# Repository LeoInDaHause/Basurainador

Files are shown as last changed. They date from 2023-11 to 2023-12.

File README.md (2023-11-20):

# Integrantes
Cesar Leonardo Rodriguez León

Diego Fernando Carvajal Lagos

Jhohan Stiven Rodriguez Rodriguez

# BASURA-INADOR

Este proyecto que tiene como objetivo central crear una cultura positiva alrededor de las basuras, en esto se trata sobre el reciclaje y el manejo de las basuras. con el objetivo de lograr esto se crea un "artefacto" que sea didactico y que llame la atención de niños entre los 5 a 7 años.

Para lograr construir este proyecto "artefacto", se a realizado una investigación previa, alrededor de la cultura y de como contruir esta cultura en los niños. y tambien se realizo una investigación sobre los materiales para usar, y de la manera mas eficiente de conseguir este artefacto.

las concluciones obtenidas de estas investigaciones son:

1. Por parte de lo cultural, se identificó que la mejor manera de crear una cultura en los niños eran son estímulos que a estos les llamara la atención, por ejemplo luces y sonidos.

2. A partir de la investigación realizada para temas de material y eficiencia del proyecto, de decide el uso de un microcontrolador, junto a un sensor de color, luces led, y sonidos.

En un principio se tenia la idea de realizar 3 canecas de basura que tubieran el objetivo de separar las basuras, en organicos, papel y carton, y metales y vidrios. A medida que fue avanzando el tiempo el proyecto cada vez era mas pulido. hasta el punto en el que unicamente se utilizaria una caneca, y a partir de esto, mediante una pantalla(lcd o oled), se le pidiera al usuario ingresear un tipo de basura, mediante un sensor (TCS3200) detectaria el color de la basura y determinaria, mediante un programa desde el microcontrolador (ESP32), si este elemento es el solicitado o no. en caso de que el elemento fuera correcto, este arrojaria la LUZ del elemento y produciria un sonido "positivo", y habriria la tapa de la caneca, en caso contrario este arrojaria una LUZ diferente al elemento y produciria un sonido "malo", y la tapa no habriría.

De esta manera se espera que el niño de 5 a 7 años interactue con el "artefacto" sin aburrirse, y genernado en este la cultura deseada, para solucionar una problematica que se vive en la actualidad y que tiene graves consecuencias, como lo es el impacto a la salud, clima, biodiversidad, suciedad, entre otras cosas.

Las teorias que sustentan este proyecto son fisicas orientadas a la elecctronica, y sociales orientadas a la cultura.

## Teorias orientadas a la electrónica:
1. Leyes de Ohm
2. Leyes de Kirchhoff
3. Leyes de Maxwell
4. Teoria de telecomunicaciones
5. Teoria del control

## Teoria orientadas a la cultura:
1. Teoria del juego
2. Condicionamiento Clasico
3. Condicionamiento Operante
4. Teoría de la actividad de Elkonin

# Diagrama de Flujo:

Diagrama en blanco

# Diagrama de Caja negra:


# Diagrama de Tecnológico:

Basurainado diagrama refinado_page-0001

# Póster:

Plantilla_TPI pptx

# Proyecto Finalizado:

(video)

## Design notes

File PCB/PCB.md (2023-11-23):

# Creación de la PCB

Para la creación de la PCB, se empezo a realizar en las 3 ultimas semanas, esta cuando ya teniamos planteado de manera definitiva el proyecto, para el comienzo de la PCB se aprendio sobre las etiquetas utilizadas en kicat, para que se viera mas organizado la PCB:



Después, se empezaron a crear los caminos(tracks) para comunicar los componentes, en la imagen se puede ver como:









La siguiente imagen, se trata sobre el diametro de cada camino para el voltaje y los normales:



PCB ya en fisico




PCB con sus componenetes ya soldados




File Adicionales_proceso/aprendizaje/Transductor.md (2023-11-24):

Al comienzo del proceso teniamos pensado poner un parlante pequeño que trasmitiera sonidos a partir de si el elemento era correcto o no, a lo largo del proceso este objetivo quedo
al final, por lo cual la ultima semana, empezamos a cacharrear con el parlante. pero hubo un problema.

resulta que cuando poniamos el parlante en el proyecto, junto a los otros componentes, pensabamos que este como que consumia mayor voltaje haciendo que el servomotor se volviera loco y perdieramos
el control de este. por lo cual habiamos desistido debido a que ya teniamos el tiempo sobre el cuello, pero un dia antes de la presentacion, se detecto de que trataba el error.

este error se producia por un PIN

este fue por que usamos un PIN que ya estaba definido en el codigo, produciendo una mala señal y comprometiendo el servomotor
ya despues, detectado este error, se corrigio, por lo que al final nos quedamos con el PIN PWM (señal que genera al parlante para que reproduzca el sonido)

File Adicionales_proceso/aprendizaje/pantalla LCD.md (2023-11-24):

configuracion de la Pantalla LCD

con la pantalla LCD se tubo un problema con respecto a su conexion en un principio debido a que se necesitaba un cable 
especial que no se pudo conseguir, por lo que se tubo que soldar.



ya soldada los cables a la pantalla lcd se empiza a relaizar la programacion para que esta proyectara lo que queriamos,
en este caso producir un mensaje aleatorio solicitandole al usuario un elemento(basura) entre ("Organico", "Papel y Metal",
"Plastico y Vidrio"), y dependiendo de si es correcto esta daria un mensaje "Correcto" y en otro caso "Incorrecto"

https://github.com/LeoInDaHause/Basurainador/assets/145580263/93dd53f0-decb-44f5-940f-e1c6dde341c4

despues cuando se intento ya el proyecto completo hubo un fallo en la pantalla LCD, este se produjo debido a que un cable (jumper)
se habia dañado, haciendo que el computador no reconozca o no detecte la pantalla.

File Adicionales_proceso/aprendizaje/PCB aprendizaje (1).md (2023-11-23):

el proceso de la PCB, se realizo por medio de la aplicación kicad, esto debido a que nos permite hacer modelos esquematicos y de diseño, primero de hizo la programacion y conexion del circuito,todo conectado con la ESP32, despues toco escoger en cada uno de los componentes el modelo de (bluprint). despues en kicad no existia el diseño del sensor que usamos (TCS3200), por lo que toco diseñarlo, y por parte de la ESP32, se encontro el modelo por internet.

Despues se convierte el esquematico a brupint el cual hay que unir los camino de los cuales se escogieron, de igual que establecer su diametro. en este punto es muy importante por que hay que tener mucho cuidado de no cruzar los caminos, que estubieran diferentes para saber lo que iba conectado a que.

ya Finalizo el proceso de las capas de la PCB, esta se envio a una empresa en Bogotá que hace la PCB que fue diseñada, esta nos la entregan el lunes (20-11-2023) a las 5pm

ya con la PCB en nuestras manos de procedio a la soldar los componentes que le pusimos



despues de soldar, se limpio con alchol isopropilico para eliminar residuos de soldadura de nuestra PCB

https://github.com/LeoInDaHause/Basurainador/assets/145580263/677bf93b-1ecc-4082-81b1-64d2f14283ff

cuando probamos el proyecto en la PCB, no funcionaba, por lo que dudamos de si la PCB, quedo bien hecho, por lo que empezamos a mirar su continuidad

https://github.com/LeoInDaHause/Basurainador/assets/145580263/6830ea95-e548-415c-8a15-80466148f962

## Errores que tubimos en este proceso

1. en la creacion de la PCB, por medio de kicad, hubo mala conexion de los pines por lo cual arrojaba errores
2. otro problema fue el desconocimiento con la aplicacion que complico las cosas, pero con la ayuda del profesor este camino se
   fue despejando y haciendose mas facil

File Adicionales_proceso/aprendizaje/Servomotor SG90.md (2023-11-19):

mpiza la configuracion del servomotor

https://github.com/LeoInDaHause/Basurainador/assets/145580263/3488bf7d-7020-4524-8e29-eb3a34d98795

ya configurado correctamente el servomotor se prosigue con la configuacion de la pantalla LCD

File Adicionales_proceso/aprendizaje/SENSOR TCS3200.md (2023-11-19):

uando se configuro la ESP32 con el Sensor TCS3200, se empezo a detectar un problema que en un principo no sabiamos su causa, 
este problema se trataba sobre los valores que arrojaba la TCS3200 cuando se intentaba determinar un color, debido a que 
eran valores que variaban a cada segundo y de una manera aleatoria, (paralelo a esto tambien exisatian errores de programación)
esto de detecto cuando se reviso lo que sucedia en el osciloscopio.
La razón de este problema era debido al ruido que habia habia en el ambiente (luz natural o luz de los bombillos)
por lo cual nos dimos de cuenta de que para que el sensor funcione correctamente este debia de estar en cierta oscuridad, 
por lo que nuestro proyecto debe de estar en lugares cerrados.



Cuando se consiguio solucionar los problemas tanto de programacion como de iluminación, se prosiguio a hacer el servomotor

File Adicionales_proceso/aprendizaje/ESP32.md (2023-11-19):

comienza el proceso de (configurar) la ESP32 con el computador y con micropython,

ESP32 configuración

3. ya configurado la ESP32, se empieza a revisar los pines para realizar las conexiones, para esto se utilizo una Guia



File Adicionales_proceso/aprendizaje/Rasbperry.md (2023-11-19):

en un principio al empezar con el microcontrolador se empezo por una raspberry pi pico, en este proceso mediante un 
computador se utilizaron librerias que funcionaran para el Programa de programacion en este caso el usado fue Thonny.

se empieza la configuración de la raspberry

los problemas que se tubieron con la raspberry pi pico:

en este desarrollo se experimentaron diferentes problemas, debido a que se tubo que instalar diferentes archivos, 
y pedir permisos al computador para poderlos ejecutar, ya teniendo la rasbperry pi pico conectada al computador y 
a Thonny se empezo a cacharrear el funcionamiento con los pines mediante actividades durante el taller. nos guiamos
mediante el datacheet y de diferentes paginas encontradas en internet, la inmensa mayoria en ingles.

se enciende el sensor con la raspberry
se empieza a cacharrearle al sensor TCS3200, con la raspberry

Otro problema presentado fue a partir de intentar conectar los pines con los diferentes componentes en la protoboard, 
este problema se presentaba a razon de que no habia una buena conexion en la protoboard, lo que conllevaba a que 
aveces funcionaba y aveces no. En consecuencia de esto se decide soldar a los pines de la raspberry pi pico unas regletas, 
para poner conectar estas con jumpers hembra, debido a la inexperiencia la soldadura quedo mal, y la 
raspberry pi pico presento otros problemas 

pines soldados pico

despues de presentar los problemas anteriormente mencionado, se decidio en conjunto utilizar el microcontrolador ESP32, 
esto debido a que por una parte ya tiene las regletas soldadas, tambien porque esta mejor documentado por internet que 
la rasbperry pi pico, y ademas ya tiene mas bibliotecas

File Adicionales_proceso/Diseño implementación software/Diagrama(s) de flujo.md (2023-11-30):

El primer diagrama que se hizo, fue el diagrama de caja negra, este se define como un diagrma que muestra al usuario los diferentes mecanismos que hace un objeto, si recibe señales, y de esas señales también activa otras, estas señales puedes ser físicas, digitales, y lo mismo con los actuadores, y también define como este recibe energía, como transforma esa energía en señales y mensajes que recibe y manda, entre otras cosas.

Estos diagramas fueron evolucionando, a tal punto de crear un mejor diagrama de caja negra, de flujo:
Diagrama de caja negra #2:

Diagrama tecmológico:


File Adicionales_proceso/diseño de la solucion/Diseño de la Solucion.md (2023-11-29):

## Diagrama de Caja negra:


## Diagramas de Tecnológico:
# primer diagrama realizado

Basurainado diagrama refinado_page-0001

# segundo diagrama realizado

Basurainado diagrama refinado (1)

## Diagrama de Flujo:

Diagrama en blanco

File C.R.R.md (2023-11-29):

# Conclusiones
1. Para realizar un Proyecto como el que nos planteamos es necesario una Investigacion y Preparacion Posterior, de igual manera que debatir y tener una participacion activa en el proyecto.
   
2. Siempre debemos de mantener una Visión critica sobre lo que hacemos, es por esta razón que nuestra proyecto al pasar de tiempo fue variando poco a poco, mejorandolo cada vez mas. 
   
3. La prueba y error es fundamental para nuestro aprendizaje, la desesperacion y aveces un poco de estres nos permite ir mas halla de lo que creemos posible ir. a dia de hoy contamos con diferentes herramientas que nos permiten documentarnos, investigar y mejorarnos a si mismos, una de estas herramientas es la Internet, ya que es una gran fuente de conocimiento, que nos permite apoyarnos en ellas para salir de problemas en los que nos encontremos.

4. La tecnologia y en especial la Ingenieria Electronica, nos permite dar soluciones a diferentes problematicas alrededor del mundo, yendo desde lo mas tecnologico, hasta lo mas social.

5. La organizacion y un cronograma es fundamental para sacar adelante un proyecto

6. el profesor nos recomendo que cuando tubieramos problemas, miramos el problema de manera aislada, y no de manera conjunta, para esto debemos de mirar componente por componente, para identificar y aislar el problema que se nos presente

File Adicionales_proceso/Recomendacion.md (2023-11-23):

1. establecer un cronograma mas concreto
2. establecer mejor todo, y una mayor planificacion, para no gastar dinero de manera irracional
3. empezar desde el principio y no dejar gran parte a ultima hora
4. hacer pruebas en cada momento, para garantizar que el proyecto esta llendo por buen camino, y para identificar los errores a tiempo.

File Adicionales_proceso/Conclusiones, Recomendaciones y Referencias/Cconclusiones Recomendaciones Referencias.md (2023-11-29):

## Conclusiones
1. Para realizar un Proyecto como el que nos planteamos es necesario una Investigacion y Preparacion Posterior, de igual manera que debatir y tener una participacion activa en el proyecto.
   
2. Siempre debemos de mantener una Visión critica sobre lo que hacemos, es por esta razón que nuestra proyecto al pasar de tiempo fue variando poco a poco, mejorandolo cada vez mas. 
   
3. La prueba y error es fundamental para nuestro aprendizaje, la desesperacion y aveces un poco de estres nos permite ir mas halla de lo que creemos posible ir. a dia de hoy contamos con diferentes herramientas que nos permiten documentarnos, investigar y mejorarnos a si mismos, una de estas herramientas es la Internet, ya que es una gran fuente de conocimiento, que nos permite apoyarnos en ellas para salir de problemas en los que nos encontremos.

4. La tecnologia y en especial la Ingenieria Electronica, nos permite dar soluciones a diferentes problematicas alrededor del mundo, yendo desde lo mas tecnologico, hasta lo mas social.

5. La organizacion y un cronograma es fundamental para sacar adelante un proyecto

6. el profesor nos recomendo que cuando tubieramos problemas, miramos el problema de manera aislada, y no de manera conjunta, para esto debemos de mirar componente por componente, para identificar y aislar el problema que se nos presente

## Recomendaciones para proyectos futuros

1. establecer un cronograma mas concreto
   
2. establecer mejor todo, y una mayor planificacion, para no gastar dinero de manera irracional
   
3. empezar desde el principio y no dejar gran parte a ultima hora
   
4. hacer pruebas en cada momento, para garantizar que el proyecto esta llendo por buen camino, y para identificar los errores a tiempo.

## Referencias utlizadas para nuestro proyecto de investigacion

”Teor ́ıa del juego - Piaget, Vigotsky, Freud”, Web de
Psicolog ́ıa, 2019. [En l ́ınea]. Disponible: https://www.psicologia-
online.com/teoria-del-juego-piaget-vigotsky-freud-1427.html.
[  ́Ultimo acceso: 18-nov-2023]

M. Guerri, ”Skinner y en Condicionamiento Operante”,
PsicoActiva, 18-may-2023. [En l ́ınea]. Disponible:
https://www.psicoactiva.com/blog/skinner-condicionamiento-
operante/. [  ́Ultimo acceso: 18-nov-2023]

GestioPolis. “Teor ́ıa general de los sistemas”. [En l ́ınea].
Disponible en: https://www.gestiopolis.com/teoria-general-de-los-
sistemas/. [Accedido: 20-nov-2023]

Seg ́un un informe del Ministerio del Medio Ambiente de Chile,
los Objetivos de Desarrollo Sostenible (ODS) son de gran
importancia. [Enlace a la fuente: https://ods.mma.gob.cl/wp-
content/uploads/2017/06/12S panishW hyitM atters.pdf ]

Psicoactiva. (2023). Condicionamiento Cl ́asico. [Online]. Avail-
able: https://www.psicoactiva.com/blog/condicionamiento-clasico/

N ́ucleo do Conhecimento. (2023). Ense ̃nanza
del Desarrollo. [Online]. Available:
https://www.nucleodoconhecimento.com.br/educacion-
es/ensenanza-del-desarrollo/

J. Castells, "Teoría de las telecomunicaciones," Academia.edu, 2016. [En línea]. Disponible: https://www.academia.edu/29220037/Teor%C3%ADa_de_las_telecomunicaciones. [Accedido: 29-nov-2023]

"Introducción - Modelado," MdP, 2016. [En línea]. Disponible: http://www3.fi.mdp.edu.ar/control4c7/APUNTES/Clase%201%20-%20Introduccion%20-%20Modelado.pdf. [Accedido: 29-nov-2023]

"ESP32 Series Datasheet," Espressif Systems, 2023. [Online]. Available: https://www.espressif.com/sites/default/files/documentation/esp32_datasheet_en.pdf. [Accessed: 29-Nov-2023].

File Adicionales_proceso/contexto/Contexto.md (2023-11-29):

   ## Problematica

   La problematica que queremos atacar es la problematica Numero 12 : Produccion y consumo responsable. esta es una problematica planteada
   por la Organizacion de las Naciones Unidas (ONU).

  esta es una problematrica que genera otras muchas problematicas. entre estas podemos ver, por ejemplo, daño a las fuentes hidricas, daño
  a los diferentes ecosistemas, problematicas de salud, desabastecimiento de recursos naturales, sobre-explotacion de los recursos, entre
  otras problematicas

   Sabiendo que es una problematica muy amplia y que toca diferentes aspectos. como por ejemplo, abandono estatal, consumismo y falta de 
   etica por parte de diferentes multinacionles, falta de cultura de toda la ciudadania. nosotros unicamente nos enfocaremos en la Falta de cultura,
   mas especificamente en la cultura de los niños de 7 a 10 años.

   ## Objetivos

   los objetivos que tenemos planteados en nuestro proyecto, son requisitos para avanzar en el siguiente objetivo, es decir para conseguir el
   segundo objetivo primero de ha de hacer el primer objetivo.

   1. crear un artefacto que genere estimulos visuales y auditivos en niños de 5 a 7 años
   2. empezar a generar una cultura positiva entorno al reciclaje y a las basuras en niños de 5 a 7 años
   3. transformar la cultura de los mayores, con ayuda de los niños que crearon una cultura positiva de reciclaje
   4. aumentar el porcentaje de basuras recicladas y reutilizadas, en Bogotá

   ## Alcances 

   el alcance que queremos lograr con nuestro proyecto es generar en los niños de 5 a 7 años una cultura positiva entorno al reciclaje y
   a las basuras. y con esto lograr que los niños transformen la cultura de los mayores, empezando por sus padres. para finalmente como mayor alcance
   conseguir un mayor porcentaje de reciclaje y reutilizacion de las basuras que consumismos cotidianamente

   ## cronograma palnteado para la realizacion del primer objetivo

   https://www.canva.com/design/DAFuPcXsBWQ/CQxAwrTf0ytOGEh5u4aXKw/edit
   


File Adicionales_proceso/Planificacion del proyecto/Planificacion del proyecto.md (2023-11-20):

# Contextualización
En la asignatura de Introduccion a la Ingenieria Electronica, se propuso dar una solución a una de las diferentes problematicas plantadas por la ONU.

La problematica que se elijio para dar una posible solucion es Produccion y Consumo Responsable, pero esta problemática abarca diferentes campos, por lo que decidimos centrarnos en uno. la cultura de los ciudadanos alrededor de las basuras



Por lo que nos propusimos crear, mediante la Ingenieria Electrónica, un artefacto que permita generar una cultura alrededor de los documentos. 

Para crear este artefacto se realizo previamente una investigacion, las concluciones a las que llegamos fueron: 

1. Atacar la problematica que sufre nuestra sociedad sobre la cultura alrededor de las basuras, lo mas inteligente es crear una nueva cultura que empieze desde los niños (futuros adultos).

2. Como la poblacion objetivo son los niños, el artefacto que se quiere crear a de ser didactico y facil de usar, con el objetivo de que los niños no se aburran de este.

3. El artefacto en cuestion debe de generar un impacto a corto, mediano y largo plazo.

Ya teniendo en cuenta esto, se procede a empezar la planificación del proyecto.

# Planificacion del proyecto

Primero se realizaron diferentes fractales, para darnos una idea mas específica de como habia de ser orientado el proyecto. junto a una justificacion, un estado del arte, un marco teórico, y un planteamiento de la problematica, el fractal se pueden ver en el siguiente link:

https://lucid.app/lucidspark/51dd2235-cf69-4047-a6bc-4f634783bd4e/edit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

Durante el proceso, en el grupo se experimentaron diferentes debates que alimentaron de manera positiva al proyecto para ir aterrizandolo cada vez mas, en esto se debatieron como debia de ser el sistema de estimulos para atraer la atencion de los niños, tambien se debatio el uso de diferentes sensores, el material de la caneca, y tambien se debatio sobre que microcontrolador se debia de usar. 

Después, se realizo un Diagrama de caja Negra que muestra lo que debe de hacer nuestro proyecto, este diagrama de caja negra fue progresando poco a poco, de igual manera que el diagrama tecnologico. hasta llegar a su fase final

## Diagrama de caja negra:
Diagrama de caja negra

## Diagrama Tecnológico:
Basurainado diagrama refinado

# Proyecto Terminado:

(video)

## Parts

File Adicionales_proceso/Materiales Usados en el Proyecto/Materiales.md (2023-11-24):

# Materiales Usados para la Construccion del Proyecto "Artefacto"

## PCB


## ESP32



## Sensor TCS3200



## Pantalla Groove LCD RGB backlight V2.0



## Servomotor SG90



## Luces LED



## Madera MDF(fibras de densidad media)



## (posible) transductor(parlante)



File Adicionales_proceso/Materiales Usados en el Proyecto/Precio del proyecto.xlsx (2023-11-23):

COMPONENTES | REFERENCIA | CANTIDAD | UNIDAD en pesos $ | PRECIO pesos $
PCB |  | 1 | 15000 | 15000
microcontrolador | ESP32 | 1 | 32000 | 32000
Sensor | Sensor TCS3200 | 1 | 38000 | 38000
Pantalla | pantalla grove LCD RGB backlight V2.0 | 1 | 85000 | 85000
Motor | Servomotor SG90 | 1 | 12000 | 12000
Material para la caneca | Madera MDF 3mm | 8 | 4500 | 36000
Jack hembra |  | 1 | 4000 | 4000
jack macho |  | 1 | 10800 | 10800
 |  | Total | 201300 | 232800

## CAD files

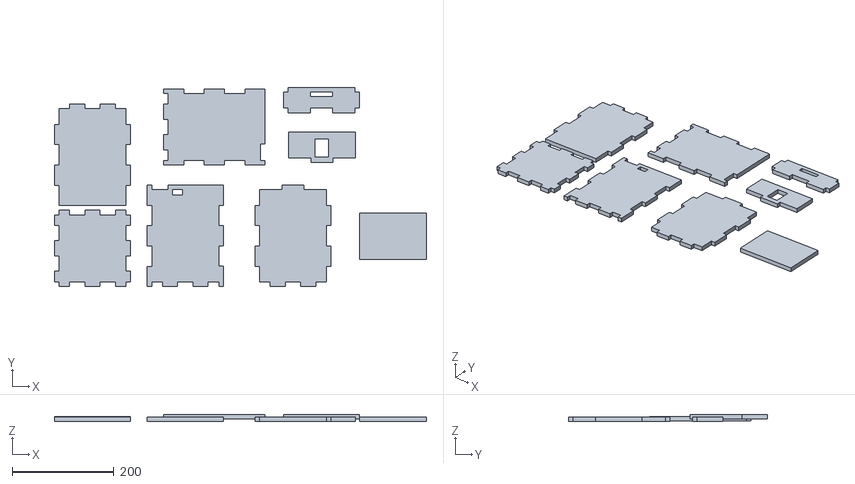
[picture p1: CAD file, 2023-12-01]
Case (Modelo)/Basurainador Modelo 3D.dxf
733.0 x 392.6 x 13.8

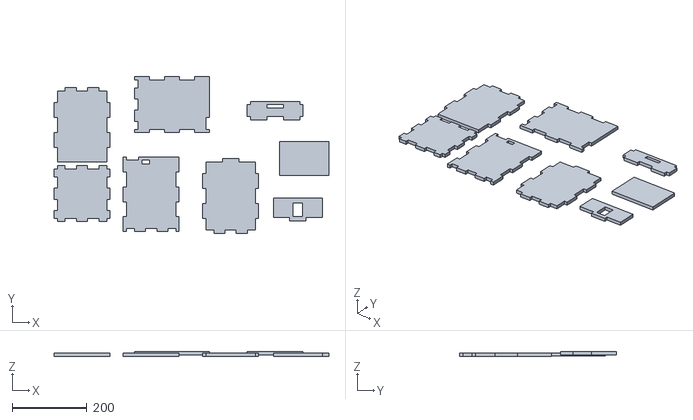
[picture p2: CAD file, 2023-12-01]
Case (Modelo)/Basurainador Modelo 5.dxf
735.0 x 419.5 x 13.8

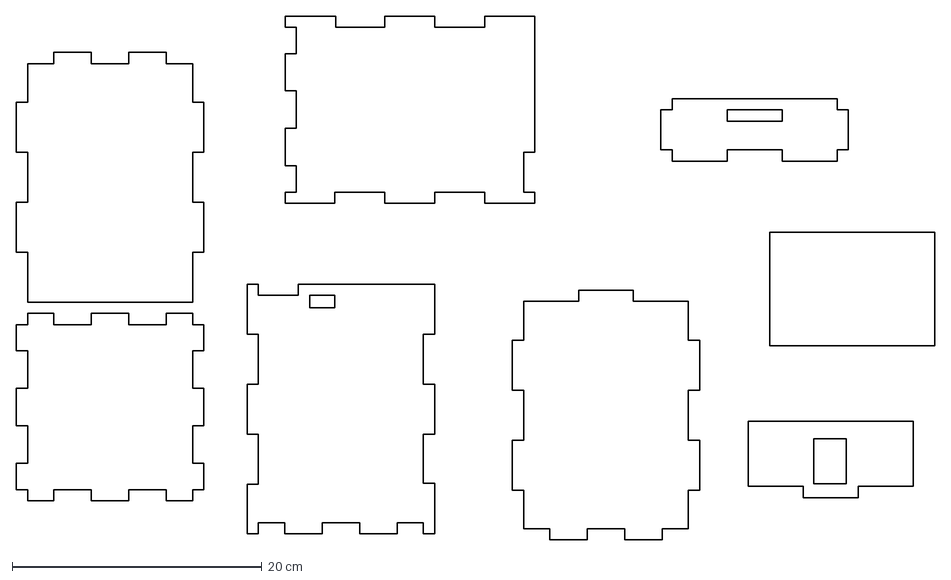
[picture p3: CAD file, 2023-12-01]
Case (Modelo)/Basurainador Corte Laser file.dxf
73.5 x 41.9 cm

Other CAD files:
Case (Modelo)/Modelo 2D.dwg
Case (Modelo)/Modelo 3D B1.dwg
Case (Modelo)/Basurainador Modelo 3D.dwg
Case (Modelo)/Modelo 3D A1.skp

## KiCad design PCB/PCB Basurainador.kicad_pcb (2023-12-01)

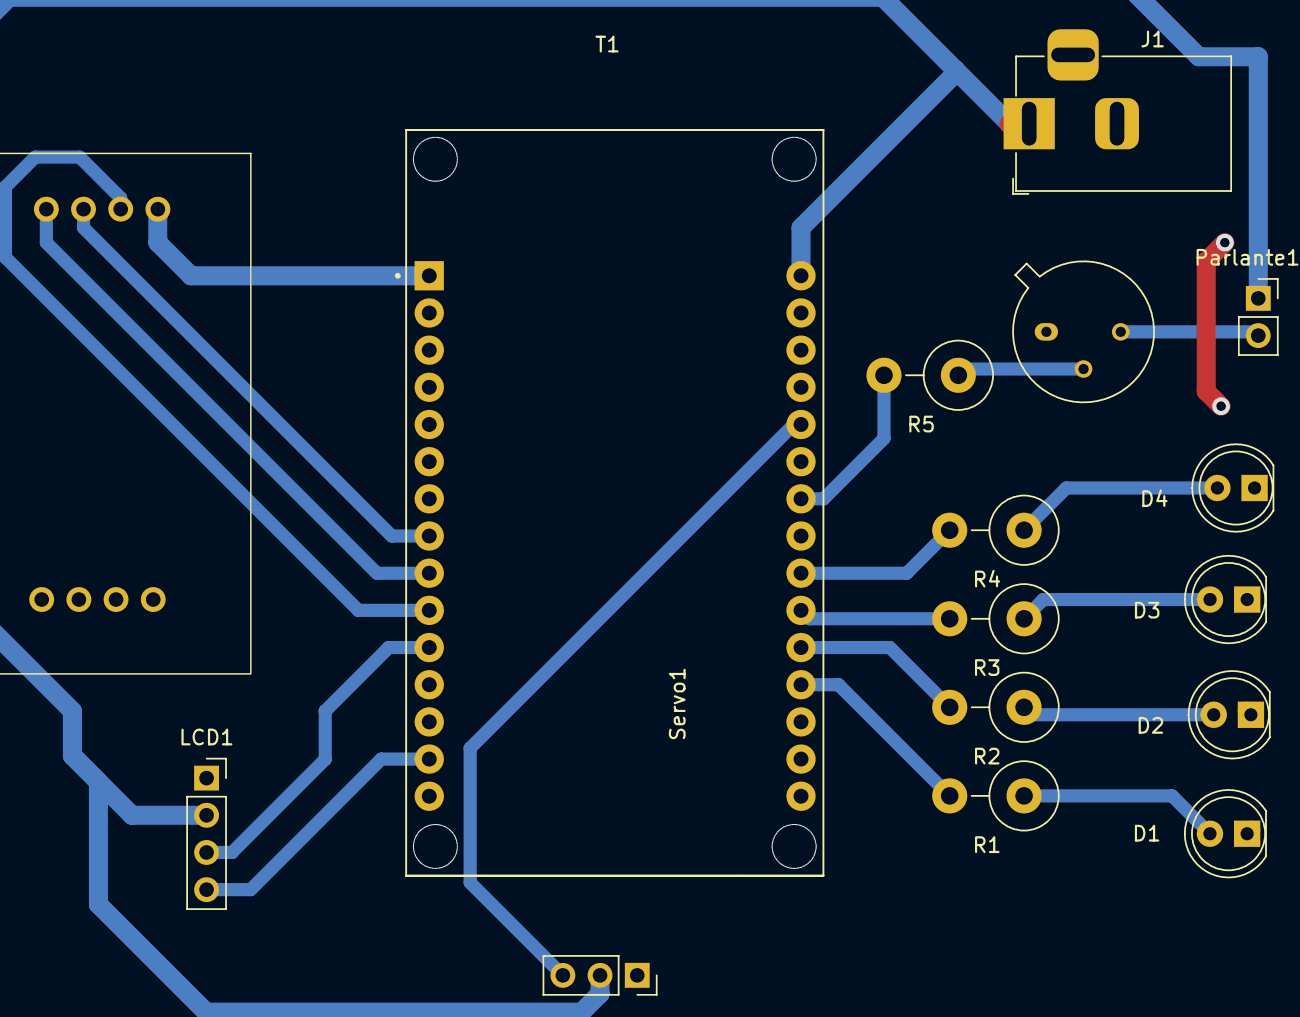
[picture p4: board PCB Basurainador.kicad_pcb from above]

Board: 2 copper layers, 16 parts (0 on the bottom side), 18 nets.

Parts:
D1, D2, D3, D4: LED; LED_D5.0mm
J1: Barrel Jack; BarrelJack_Horizontal
LCD1: Conn_01x04_Socket; PinSocket_1x04_P2.54mm_Vertical
Parlante1: Conn_01x02_Socket; PinSocket_1x02_P2.54mm_Vertical
R1, R2, R3, R4, R5: R; R_Axial_DIN0414_L11.9mm_D4.5mm_P5.08mm_Vertical
Servo1: Conn_01x03_Socket; PinSocket_1x03_P2.54mm_Vertical
T1: 2N2222A; TO-39-3
U1: ESP32-DEVKIT-V1; MODULE_ESP32_DEVKIT_V1
U2: TCS3200; SOIC127P600X175-8N

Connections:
+3V3: U1.1 (3V3), U2.8 (S3)
+5V: J1.1, LCD1.2, Parlante1.1, Servo1.2, U1.30 (VIN)
/D5: U1.8 (D5), U2.6 (OUT)
/D14: Servo1.3, U1.26 (D14)
/D18: U1.9 (D18), U2.5 (VDD)
/D19: U1.10 (D19), U2.7 (S2)
/D21: LCD1.3, U1.11 (D21)
/D22: LCD1.4, U1.14 (D22)
/D32: R4.2, U1.22 (D33)
/D33: R3.2, U1.21 (D32)
/D34: R2.2, U1.20 (D35)
/D35: R1.2, U1.19 (D34)
/P1: Parlante1.2, T1.3 (C)
GND: D1.1 (K), D2.1 (K), D3.1 (K), D4.1 (K), J1.2, J1.3, LCD1.1, Servo1.1, T1.1 (E), U1.2 (GND), U1.29 (GND), U2.4 (GND)
unnamed: D1.2 (A), R1.1
unnamed: D2.2 (A), R2.1
unnamed: D3.2 (A), R3.1
unnamed: D4.2 (A), R4.1

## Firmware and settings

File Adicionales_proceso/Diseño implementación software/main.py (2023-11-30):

#Codigo final del basurainador:

from tcs3200 import TCS3200 
import i2c_lcd #16 por fila y 2 columnas
from servo import Servo
from machine import Pin, I2C, deepsleep, PWM
import time
import utime
from neopixel import NeoPixel
import random

#Contador Objetos
co=0
cp=0
cm=0

ob=1

# Variable para manejar la pantalla grove LCD RGB backlight V2.0

i2c = I2C(0, scl=Pin(22), sda=Pin(21), freq=400000)

# configuaracion del dispaly para manejar correctamente los datos

d = i2c_lcd.Display(i2c, lcd_addr=0x3e, rgb_addr=0x62)

# Funcion necesaria para manejar los datos

d.home()

# funcion para borrar esos datos (no mostrar estos datos en la pantalla)

d.clear()

# Pines que se van a utilizar para el sensor TCS3200

tcs3200 = TCS3200(OUT=19, S2=5, S3=18, S0=17, S1=16, LED=10)

# Pines utilizados para los leds

ledb=Pin(32, Pin.OUT)
ledi=Pin(33, Pin.OUT)

ledb.off()
ledi.off()

p26 = Pin(26, Pin.OUT)
pwm = PWM(p26)
pwm.freq(40000)

# Pin para manejar el servo

my_servo = Servo(pin_id=14)

# posicion inicial del servo, 0 = grados

my_servo.write(0)

# sale de la libreria para manejar y calibrar correctamente el sensor TCS3200

tcs3200.debugging=tcs3200.ON
tcs3200.led = tcs3200.ON

NEOPIXEL_PIN=20
NO_OF_LEDS=7

neoPixel = NeoPixel(Pin(NEOPIXEL_PIN),NO_OF_LEDS)
tcs3200.freq_divider = tcs3200.TWO_PERCENT

# Calibrar el sensor en una frecuencia de negro y blanco, lo solicito lo solicita la libreria

black_freq = [2890.257, 2601.051, 3495.77, 9454.477]
white_freq = [15283.51, 15494.27, 14985.76, 11150.76]
tcs3200.calibrateSet(black_freq,white_freq)

# Funcion para que la pantalla LCD, varie 2 veces entre los colores azul, verde, rojo y despues quede en color gris

def color():
    for i in range(2):
        d.color(0, 0, 255)  # Azul
        time.sleep(0.5)
        d.color(0, 255, 0)  # Verde
        time.sleep(0.5)
        d.color(255, 0, 0)  # Rojo
        time.sleep(0.5)
    d.color(128, 128, 128)
    
# la funcion random_color y celebrate hace que cuando el usuario ya halla propiciado el elemento correcto, la pantalla,
# parpadea de diferentes colores
    
def random_color():
    return (random.randint(0, 255), random.randint(0, 255), random.randint(0, 255))

def celebrate(display, servo, duration):
    end_time = time.time() + duration
    my_servo.write(95)  # aca hace que el servomotor se mueva
    while time.time() < end_time:
        color = random_color()
        display.backlight.set_color(*color)
        time.sleep(0.5)
    my_servo.write(0)  # aca hace que el servomotor se mueva
    
def celebrate2(display, servo, duration):
    end_time = time.time() + duration
    my_servo.write(0)
    sleep_time = duration / 90  # divide the duration by the number of degrees
    for angle in range(90):  # loop from 0 to 90
        if time.time() > end_time:
            break
        color = random_color()
        display.backlight.set_color(*color)
        my_servo.write(angle)  # write the current angle to the servo
        time.sleep(sleep_time)  # sleep for the calculated time
    
def sonido_acierto():
    pwm = PWM(p26)
    pwm.freq(40000000)  # Frecuencia de 40 MHz
    pwm.duty(512) 
    notas2=[523, 659, 784, 880, 0, 880, 784, 659, 523]
    for nota in notas2:
        if nota != 0: # Si la nota es 0, hace una pausa
            pwm.freq(nota) # Cambia la frecuencia del PWM a la de la nota
        else:
            pwm.duty(0) # Si la nota es 0, detiene el PWM
        time.sleep(0.1) # Espera un poco antes de reproducir la siguiente nota
        pwm.duty(512) # Reinicia el ciclo de trabajo del PWM para la siguiente nota
    pwm.deinit()
    
def sonido_desacierto():
    pwm = PWM(p26)
    pwm.freq(40000000)  # Frecuencia de 40 MHz
    pwm.duty(512) 
    notas3 = [523, 494, 466, 440, 0, 440, 466, 494, 523]
    for nota in notas3:
        if nota != 0: # Si la nota es 0, hace una pausa
            pwm.freq(nota) # Cambia la frecuencia del PWM a la de la nota
        else:
            pwm.duty(0) # Si la nota es 0, detiene el PWM
        time.sleep(0.1) # Espera un poco antes de reproducir la siguiente nota
        pwm.duty(512) # Reinicia el ciclo de trabajo del PWM para la siguiente nota
    pwm.deinit()
    
def sonido_fiesta():
    pwm = PWM(p26)
    pwm.freq(40000000)  # Frecuencia de 40 MHz
    pwm.duty(512) 
    notas3 = [294,0,294,587,587,587,440,440,440,0,415,415,0,392,392,0,349,349,0,294,349,349,392,262,0,262,587,587,587,440,440,440,0,415,415,0,392,392,0,349,349,0,294,349,349,392,247,0,247,587,587,587,440,440,440,0,415,415,0,392,392,0,349,349,0,294,349,349,392,233,0,233,587,587,587,440,440,440,0,415,415,0,392,392,0,349,349,0,294,349,349,392,]
    for nota in notas3:
        if nota == 0: # Si la nota es 0, hace una pausa
            continue
        pwm.freq(nota) # Cambia la frecuencia del PWM a la de la nota
        time.sleep(0.07) # Espera un poco antes de reproducir la siguiente nota
        pwm.duty(512) # Reinicia el ciclo de trabajo del PWM para la siguiente nota
    pwm.deinit()
    
# Funcion para crear un random entre los valores del 1 al 3, que muestre en la pantalla el mensaje "Ingrese un elemento papel o cartón" ,
#"Ingrese un elemento organico"   o "Ingrese un elemento plástico, metal o vidrio"
    
def assign_random_number():
    ledb.off()
    ledi.off()
    global P, O, M, rojo, verde, azul
    if co<ob and cp<ob and cm<ob:
        numero = random.randint(1, 3)
    if co>=ob and cp<ob and cm<ob:
        numero = random.choice([1, 3])
    if cp>=ob and co<ob and cm<ob:
        numero = random.randint(2, 3)
    if cm>=ob and cp<ob and co<ob:
        numero = random.randint(1, 2)
    
    if co>=ob and cp>=ob and cm<ob:
        numero = 3
    if cp>=ob and cm>=ob and co<ob:
        numero = 2
    if cm>=ob and co>=ob and cp<ob:
        numero = 1
    
    if co==ob and cp==ob and cm==ob:
        d.clear()
        d.write('GANASTE!! :D')
        sonido_fiesta()
        celebrate2(d, my_servo, 3)
        time.sleep(3)
        deepsleep()
    elif numero == 1:
        print('Ingrese un elemento papel o cartón')
        d.home()
        d.clear()
        d.write('Ingrese P o C')   # lo muestra en la pantalla LCD
        color()
        P=True
        O=False
        M=False
        rojo=False
        verde=False
        azul=False
    elif numero == 2:
        print('Ingrese un elemento organico')
        d.home()
        d.clear()
        d.write('Ingrese O')   # lo muestra en la pantalla LCD
        color()
        P=False
        O=True
        M=False
        rojo=False
        verde=False
        azul=False
    elif numero == 3:
        print('Ingrese un elemento P, M o V')
        d.home()
        d.clear()
        d.write('Ingrese P, M o V')   # lo muestra en la pantalla LCD
        color()
        P=False
        O=False
        M=True
        rojo=False
        verde=False
        azul=False

assign_random_number()
time.sleep(1)

# esto es lo que va a hacer el programa como tal, todo el tiempo

while True:
    print(co,cp,cm)

    
    time.sleep(2)  # en un tiempo de 2 segundo el sensor va a tomar datos RGB
    rgb = tcs3200.rgb
    for i in range(NO_OF_LEDS):
        neoPixel[i] = (rgb[0],rgb[1],rgb[2])
    neoPixel.write()
    if rgb[0]>10 and rgb[0]>rgb[1] and rgb[0]>rgb[2]:  # es ROJO, si se cumplen las condiciones
        rojo=True
        verde=False
        azul=False
        print('Rojo')
    if rgb[2]>10 and rgb[2]>rgb[1] and rgb[2]>rgb[0]:  # es AZUL, si se cumplen las condiciones
        verde=False
        azul=True
        rojo=False
        print('Azul')
    if rgb[1]>20 and rgb[1]>rgb[0] and rgb[1]>rgb[2]:  # es VERDE, si se cumplen las condiciones
        verde=True
        azul=False
        rojo=False
        print('Verde')
    if O==True:
        if verde==True:
            print("Correcto")
            d.home()
            d.clear()
            d.write('¡Correcto!')  # imprime en la pantalla "CORRECTO"
            co+=1
            sonido_acierto()
            celebrate(d, my_servo, 3)  # Celebrar durante 3 segundos y el servo se mueve
            time.sleep(1)
            ledb.on()
            ledi.off()
            assign_random_number()
            
        elif azul==True or rojo==True:
            print("Incorrecto")
            d.home()
            d.clear()
            d.write('Incorrecto :(')  # Imprime en la pantalla "INCORRECTO"
            d.color(255, 255, 0)
            sonido_desacierto()
            time.sleep(3)
            ledb.off()
            ledi.on()
            assign_random_number()
    if M==True:
        if rojo==True:
            print("Correcto")
            d.home()
            d.clear()
            d.write('¡Correcto!')  # imprime en la pantalla "CORRECTO"
            cm+=1
            sonido_acierto()
            celebrate(d, my_servo, 3)  # Celebrar durante 3 segundos y el servo se mueve
            time.sleep(1)
            ledb.on()
            ledi.off()
            assign_random_number()
        elif azul==True or verde==True:
            print("Incorrecto")
            d.home()
            d.clear()
            d.write('Incorrecto :(')  # Imprime en la pantalla "INCORRECTO"
            d.color(255, 255, 0)
            sonido_desacierto()
            time.sleep(3)
            ledb.off()
            ledi.on()
            assign_random_number()
    if P==True:
        if azul==True:
            print("Correcto")
            d.home()
            d.clear()
            d.write('¡Correcto!')  # imprime en la pantalla "CORRECTO"
            cp+=1
            sonido_acierto()
            celebrate(d, my_servo, 3)  # Celebrar durante 3 segundos y mueve el servo
            time.sleep(3)
            
            ledb.on()
            ledi.off()
            assign_random_number()
        elif rojo==True or verde==True:
            print("Incorrecto")
            d.home()
            d.clear()
            d.write('Incorrecto :(')  # imprime en la pantalla "INCORRECTO"
            d.color(255, 255, 0)
            sonido_desacierto()
            time.sleep(3)
            ledb.off()
            ledi.on()
            assign_random_number()
    time.sleep(1)

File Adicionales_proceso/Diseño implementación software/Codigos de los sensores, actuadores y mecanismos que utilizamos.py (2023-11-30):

# LIBRERIAS

 # esta libreria se utiliza para el sensor TCS3200, para que capte bien los colores RGB
from tcs3200 import TCS3200
# esta libreria se utiliza para manejar la pantalla LCD de 4 pines  #16 por fila y 2 columnas
import i2c_lcd
# esta libreria es para manejar el servomotor SG90
from servo import Servo
# esta libreria se utiliza para definir los pines de la ESP32 relacionarlos con la LCD
from machine import Pin, I2C
# tiempo
import time
# tiempo en microsegundo
import utime
# Manejar cosas del sensor
from neopixel import NeoPixel
# Random
import random

#Codigo Para el manejo del sensor de color TCS3200:
from tcs3200 import TCS3200 
from neopixel import NeoPixel
tcs3200 = TCS3200(OUT=19, S2=5, S3=18, S0=17, S1=33, LED=10)
tcs3200.debugging=tcs3200.ON
tcs3200.led = tcs3200.ON
NEOPIXEL_PIN=26
NO_OF_LEDS=7

neoPixel = NeoPixel(Pin(NEOPIXEL_PIN),NO_OF_LEDS)
tcs3200.freq_divider = tcs3200.TWO_PERCENT

black_freq = [2890.257, 2601.051, 3495.77, 9454.477]
white_freq = [15283.51, 15494.27, 14985.76, 11150.76]
tcs3200.calibrateSet(black_freq,white_freq)

rgb = tcs3200.rgb
for i in range(NO_OF_LEDS):
    neoPixel[i] = (rgb[0],rgb[1],rgb[2])
neoPixel.write()

#Código para la LCD y su funcionamiento en el prototipo
import i2c_lcd #16 por fila y 2 columnas
from machine import Pin, I2C
i2c = I2C(0, scl=Pin(22), sda=Pin(21), freq=400000)
d = i2c_lcd.Display(i2c, lcd_addr=0x3e, rgb_addr=0x62)
d.home()
d.clear()

def color():
    for i in range(2):
        d.color(0, 0, 255)  # Azul
        time.sleep(0.5)
        d.color(0, 255, 0)  # Verde
        time.sleep(0.5)
        d.color(255, 0, 0)  # Rojo
        time.sleep(0.5)
    d.color(128, 128, 128)

d.write('Ingrese Papel')

#Código para la asignación y clasificación de los colores por medio de ranjos del sensor TCS3200
    if rgb[0]>10 and rgb[0]>rgb[1] and rgb[0]>rgb[2]:
        rojo=True
        verde=False
        azul=False
        print('Rojo')
    if rgb[2]>10 and rgb[2]>rgb[1] and rgb[2]>rgb[0]:
        verde=False
        azul=True
        rojo=False
        print('Azul')
    if rgb[1]>20 and rgb[1]>rgb[0] and rgb[1]>rgb[2]:
        verde=True
        azul=False
        rojo=False
        print('Verde')

#Código para el funcionamiento de elegir un elemento al azar en el prototipo
import random
def assign_random_number():
    global P, O, M, rojo, verde, azul
    numero = random.randint(1, 3)
    if numero == 1:
        print('Ingrese un elemento papel o cartón')
        d.home()
        d.clear()
        d.write('Ingrese Papel')
        color()
        P=True
        O=False
        M=False
        rojo=False
        verde=False
        azul=False
    elif numero == 2:
        print('Ingrese un elemento organico')
        d.home()
        d.clear()
        d.write('Ingrese Organico')
        color()
        P=False
        O=True
        M=False
        rojo=False
        verde=False
        azul=False
    else:
        print('Ingrese un elemento plástico, metal o vidrio')
        d.home()
        d.clear()
        d.write('Ingrese Plastico')
        color()
        P=False
        O=False
        M=True
        rojo=False
        verde=False
        azul=False

assign_random_number()

#Código para encender un led en el prototipo
from machine import Pin

ledr=Pin(15, Pin.OUT)
ledg=Pin(2, Pin.OUT)
ledb=Pin(4, Pin.OUT)
ledi=Pin(23, Pin.OUT)

#Codigo para el manejo del servomotor en el prototipo
from servo import Servo
from machine import Pin
import time
my_servo = Servo(pin_id=14)
my_servo.write(127)
my_servo.write(210)
my_servo.write(127)

#Proceso para que el elemento identifique el color correcto e incorrecto:
    if O==True:
        if verde==True:
            print("Correcto")
            d.home()
            d.clear()
            d.write('¡Correcto!')
            ledg.on()
            celebrate(d, my_servo, 3)  # Celebrar durante 2 segundos
            time.sleep(1)
            ledr.off()
            ledg.off()
            ledb.off()
            ledi.off()
            assign_random_number()
            
        elif azul==True or rojo==True:
            print("Incorrecto")
            d.home()
            d.clear()
            d.write('Incorrecto :(')
            d.color(255, 255, 0)
            ledi.on()
            time.sleep(3)
            ledr.off()
            ledg.off()
            ledb.off()
            ledi.off()
            assign_random_number()
    if M==True:
        if rojo==True:
            print("Correcto")
            d.home()
            d.clear()
            d.write('¡Correcto!')
            ledr.on()
            celebrate(d, my_servo, 3)  # Celebrar durante 2 segundos
            time.sleep(1)
            ledr.off()
            ledg.off()
            ledb.off()
            ledi.off()
            assign_random_number()
        elif azul==True or verde==True:
            print("Incorrecto")
            d.home()
            d.clear()
            d.write('Incorrecto :(')
            d.color(255, 255, 0)
            ledi.on()
            time.sleep(3)
            ledr.off()
            ledg.off()
            ledb.off()
            ledi.off()
            assign_random_number()
    if P==True:
        if azul==True:
            print("Correcto")
            d.home()
            d.clear()
            d.write('¡Correcto!')
            ledb.on()
            celebrate(d, my_servo, 3)  # Celebrar durante 2 segundos
            time.sleep(3)
            ledr.off()
            ledg.off()
            ledb.off()
            ledi.off()
            assign_random_number()
        elif rojo==True or verde==True:
            print("Incorrecto")
            d.home()
            d.clear()
            d.write('Incorrecto :(')
            d.color(255, 255, 0)
            ledi.on()
            time.sleep(3)
            ledr.off()
            ledg.off()
            ledb.off()
            ledi.off()
            assign_random_number()
    time.sleep(1)

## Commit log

2023-11-14 Create sensor TCS3200
2023-11-14 Create ESP32
2023-11-18 Create Proceso de Planeación
2023-11-18 Update and rename Proceso de Planeación to Proceso de Planeación.md
2023-11-18 Update Proceso de Planeación.md
2023-11-18 Create Materiales Usados.md
2023-11-18 Create Codigos ESP32
2023-11-19 Create Rasbperry Pi Pico.md
2023-11-19 Rename Rasbperry Pi Pico to Rasbperry.md
2023-11-19 Create SENSOR TCS3200.md
2023-11-19 Create Servomotor SG90.md
2023-11-19 Update SENSOR TCS3200.md
2023-11-19 Create PCB aprendizaje.md
2023-11-19 Update PCB aprendizaje.md
2023-11-23 Create Sensor TC3200
2023-11-23 Update and rename encender un led en el prototipo.py to Encender un led en el prototipo.py
2023-11-23 Update and rename manejo del servomotor.py to Manejo del servomotor.py
2023-11-23 Update and rename proceso para que indique el correcto o el incorrecto.py to Proceso para que indique el correcto o el incorrecto.py
2023-11-29 Create Diseño de la Solucion.md
2023-11-29 Update Diseño de la Solucion.md
2023-11-30 Rename cbcb.txt to Diagrama(s) de flujo.txt
2023-11-30 Update Diagrama(s) de flujo.txt
2023-11-30 Update and rename Diagrama(s) de flujo.txt to Diagrama(s) de flujo.md
2023-11-30 Update Diagrama(s) de flujo.md
2023-11-30 Create Codigos de los sensores, actuadores y mecanismos que utilizamos.py
2023-11-30 Update Codigos de los sensores, actuadores y mecanismos que utilizamos.py
2023-12-01 git push
    [Precio del proyecto.xlsx]
